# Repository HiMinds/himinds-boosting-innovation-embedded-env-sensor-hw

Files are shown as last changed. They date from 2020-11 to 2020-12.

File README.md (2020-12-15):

# himinds-env-sensor-hw
HiMinds Open Source Wireless Environmental Sensor HW.

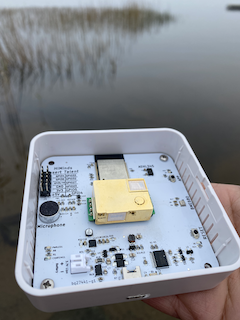
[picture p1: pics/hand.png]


## Rev B (G2)
The second generation of the hardware is based on the first version of the hardware but we have made several improvements. It is a rechargeable battery-operated wireless sensor that can measure:

* Carbon dioxide (CO₂) levels
* Temperature with ±1.0°C accuracy
* Barometric pressure with 1 hPa absolute accuracy
* Humidity with ±3% accuracy
* Volatile organic compounds (VOC) gas sensor
* Tamper detection
* Sound level meter 

The project is described in our [Medium articles](https://medium.com/himinds/himinds-wireless-environmental-sensor-gen-2-part-1-requirements-37ee416b31b).

The enclosure is called CBRS01VWH and is made by [CamdenBoss](https://www.camdenboss.com/). 

## Rev A (G1)

The first version of the hardware, was based on the work done by OLIMEX. Link to their [project page](https://github.com/OLIMEX/ESP32-DevKit-LiPo)
For other credits please refer to our [Medium ariticles](https://medium.com/himinds/open-source-wireless-environmental-sensor-part-1-requirements-8598c5b5f503).

## Open Source Hardware
The hardware is certified by OSHWA’s Open Source Hardware Certification program.
It is the first certification given to a Swedish project. 
* Rev A (Version 1.0) [OSHWA certification](https://certification.oshwa.org/se000001.html)
* Rev B (Version 2.0) [OSHWA certification](https://certification.oshwa.org/se000007.html)

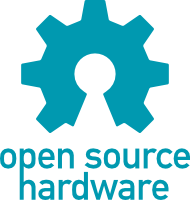
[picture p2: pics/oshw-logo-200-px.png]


## License
* Hardware is released under Apache 2.0 License
* Documentation is released under CC BY-SA 3.0

## Disclaimer of Warranties and Limitation of Liability. (from CC 3.0)

### Representations, Warranties and Disclaimer

UNLESS OTHERWISE MUTUALLY AGREED TO BY THE PARTIES IN WRITING, LICENSOR OFFERS THE WORK AS-IS AND MAKES NO REPRESENTATIONS OR WARRANTIES OF ANY KIND CONCERNING THE WORK, EXPRESS, IMPLIED, STATUTORY OR OTHERWISE, INCLUDING, WITHOUT LIMITATION, WARRANTIES OF TITLE, MERCHANTIBILITY, FITNESS FOR A PARTICULAR PURPOSE, NONINFRINGEMENT, OR THE ABSENCE OF LATENT OR OTHER DEFECTS, ACCURACY, OR THE PRESENCE OF ABSENCE OF ERRORS, WHETHER OR NOT DISCOVERABLE. SOME JURISDICTIONS DO NOT ALLOW THE EXCLUSION OF IMPLIED WARRANTIES, SO SUCH EXCLUSION MAY NOT APPLY TO YOU.

### Limitation on Liability. 
EXCEPT TO THE EXTENT REQUIRED BY APPLICABLE LAW, IN NO EVENT WILL LICENSOR BE LIABLE TO YOU ON ANY LEGAL THEORY FOR ANY SPECIAL, INCIDENTAL, CONSEQUENTIAL, PUNITIVE OR EXEMPLARY DAMAGES ARISING OUT OF THIS LICENSE OR THE USE OF THE WORK, EVEN IF LICENSOR HAS BEEN ADVISED OF THE POSSIBILITY OF SUCH DAMAGES.

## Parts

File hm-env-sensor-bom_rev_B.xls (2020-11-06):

Id | Designator | Package | Quantity | Designation
1 | C22,C21,C20,C18 | C_0603_5MIL_DWS | 4 | 10uF/6.3V/X7R/C0603
2 | J1 | PinHeader_2x06_P2.54mm_Vertical | 1 | Conn_02x06_Odd_Even
3 | U7 | PDSO-N12 | 1 | BQ27441-G1
4 | USB-UART1 | USB_Micro_B_Male_UJ2-MIBH-4-SMT-TR | 1 | MISB-SWMM-5B-LF(USB_MICRO)
5 | U11 | Texas_S-PVSON-N10_ThermalVias | 1 | TPS61202DRC
6 | U10 | SOT-353_SC-70-5 | 1 | MAX4466
7 | U9 | SOT-23-5 | 1 | SY8089AAAC(SOT23-5)
8 | U8 | MH-Z19B | 1 | MH-Z19B
9 | U6 | Bosch_LGA-8_3x3mm_P0.8mm_ClockwisePinNumbering | 1 | BME680
10 | U4 | SOT-23-5 | 1 | BL4054B-42TPRN(SOT23-5)
11 | U3 | SOT23-3 | 1 | BAT54C(SOT23-3)
12 | U2 | SSOP-20W | 1 | CH340T(SSOP20W)
13 | U1 | LGA-14_3x5mm_P0.8mm_LayoutBorder1x6y | 1 | ADXL345
14 | R33,R32,R11,R14 | R_0603_5MIL_DWS | 4 | NA/R0603
15 | R31 | R_0603_5MIL_DWS | 1 | 10k
16 | R30 | R_0603_5MIL_DWS | 1 | 20k/R0603
17 | R29,R25,R23,R5,R4,R13 | R_0603_5MIL_DWS | 6 | 1k/R0603
18 | R28,R27 | R_0603_5MIL_DWS | 2 | 1M/R0603
19 | R21 | R_0603_5MIL_DWS | 1 | 1.1k/1%/R0603
20 | R20,R17,R16,R15,R8 | R_0603_5MIL_DWS | 5 | 4.7k/R0603
21 | R19,R9,R7,R26 | R_0603_5MIL_DWS | 4 | 10k/R0603
22 | R18 | R_1206_5MIL_DWS | 1 | 0.01/1%/R1206
23 | R12 | R_0603_5MIL_DWS | 1 | 4.99k/1%/R0603
24 | R10 | R_0603_5MIL_DWS | 1 | 2.2k/R0603
25 | R6,R3,R2 | R_0603_5MIL_DWS | 3 | 220R/R0603
26 | R1,R22,R24 | R_0603_5MIL_DWS | 3 | 330/R0603
27 | Q3,Q2 | SOT23 | 2 | BC817-40(SOT23)
28 | Q1 | TSX-3.2x2.5mm_GND(3) | 1 | Q12MHz/20pF/10ppm/4P/3.2x2.5mm
29 | PWRLED1,D4 | LED_0603_KA | 2 | LED/GREEN/0603
30 | MK1 | MIC_CMA-4544PF-W | 1 | Microphone
31 | L2 | L_Wuerth_MAPI-3015 | 1 | LPS3015-222ML
32 | L1 | CD32 | 1 | 2.2uH/1.5A/DCR<0.1R/CD32
33 | FET1 | SOT23 | 1 | WPM2015-3/TR
34 | FB2,FB1 | L_0603_5MIL_DWS | 2 | Ferrite_Bead_Small
35 | D2,D1 | SMA-KA | 2 | 1N5822/SS34/SMA
36 | CHARGING1 | LED_0603_KA | 1 | LED/YELLOW/0603
37 | C19 | C_0603_5MIL_DWS | 1 | 1uF/6.3V/X7R/C0603
38 | C17,C12,C7 | C_0805_5MIL_DWS | 3 | 47uF/6.3V/20%/X5R/C0805
39 | C16 | C_0603_5MIL_DWS | 1 | 100pF/C0603
40 | C15 | C_0603_5MIL_DWS | 1 | 10uF/C0603
41 | C14 | C_0603_5MIL_DWS | 1 | 10nF/50V/20%/Y5V/C0603
42 | C13,C9,C8,C6,C2 | C_0603_5MIL_DWS | 5 | 100nF/50V/20%/Y5V/C0603
43 | C11 | C_0603_5MIL_DWS | 1 | 0.47uF/50V/20%/Y5V/C0603
44 | C10 | C_0603_5MIL_DWS | 1 | 1.0uF/16V/10%/Y5V/C0603
45 | C5 | C_0603_5MIL_DWS | 1 | 22uF/6.3V/20%/X5R/C0603
46 | C4,C3 | C_0603_5MIL_DWS | 2 | 27pF/50V/5%/C0G/C0603
47 | C1 | C_0603_5MIL_DWS | 1 | 4.7uF/50V/20%/Y5V/C0603
48 | BAT1 | LIPO_BAT-CON2DW02R | 1 | DW02S
49 | RST1,RST2 | IT1185AU2_V2 | 2 | IT-1185AU2-160G-G-TR
50 | U5 | ESP-WROOM-32_MODULE | 1 | ESP-WROOM-32
51 | D6 | LED_0603_KA | 1 | LED/RED/0603

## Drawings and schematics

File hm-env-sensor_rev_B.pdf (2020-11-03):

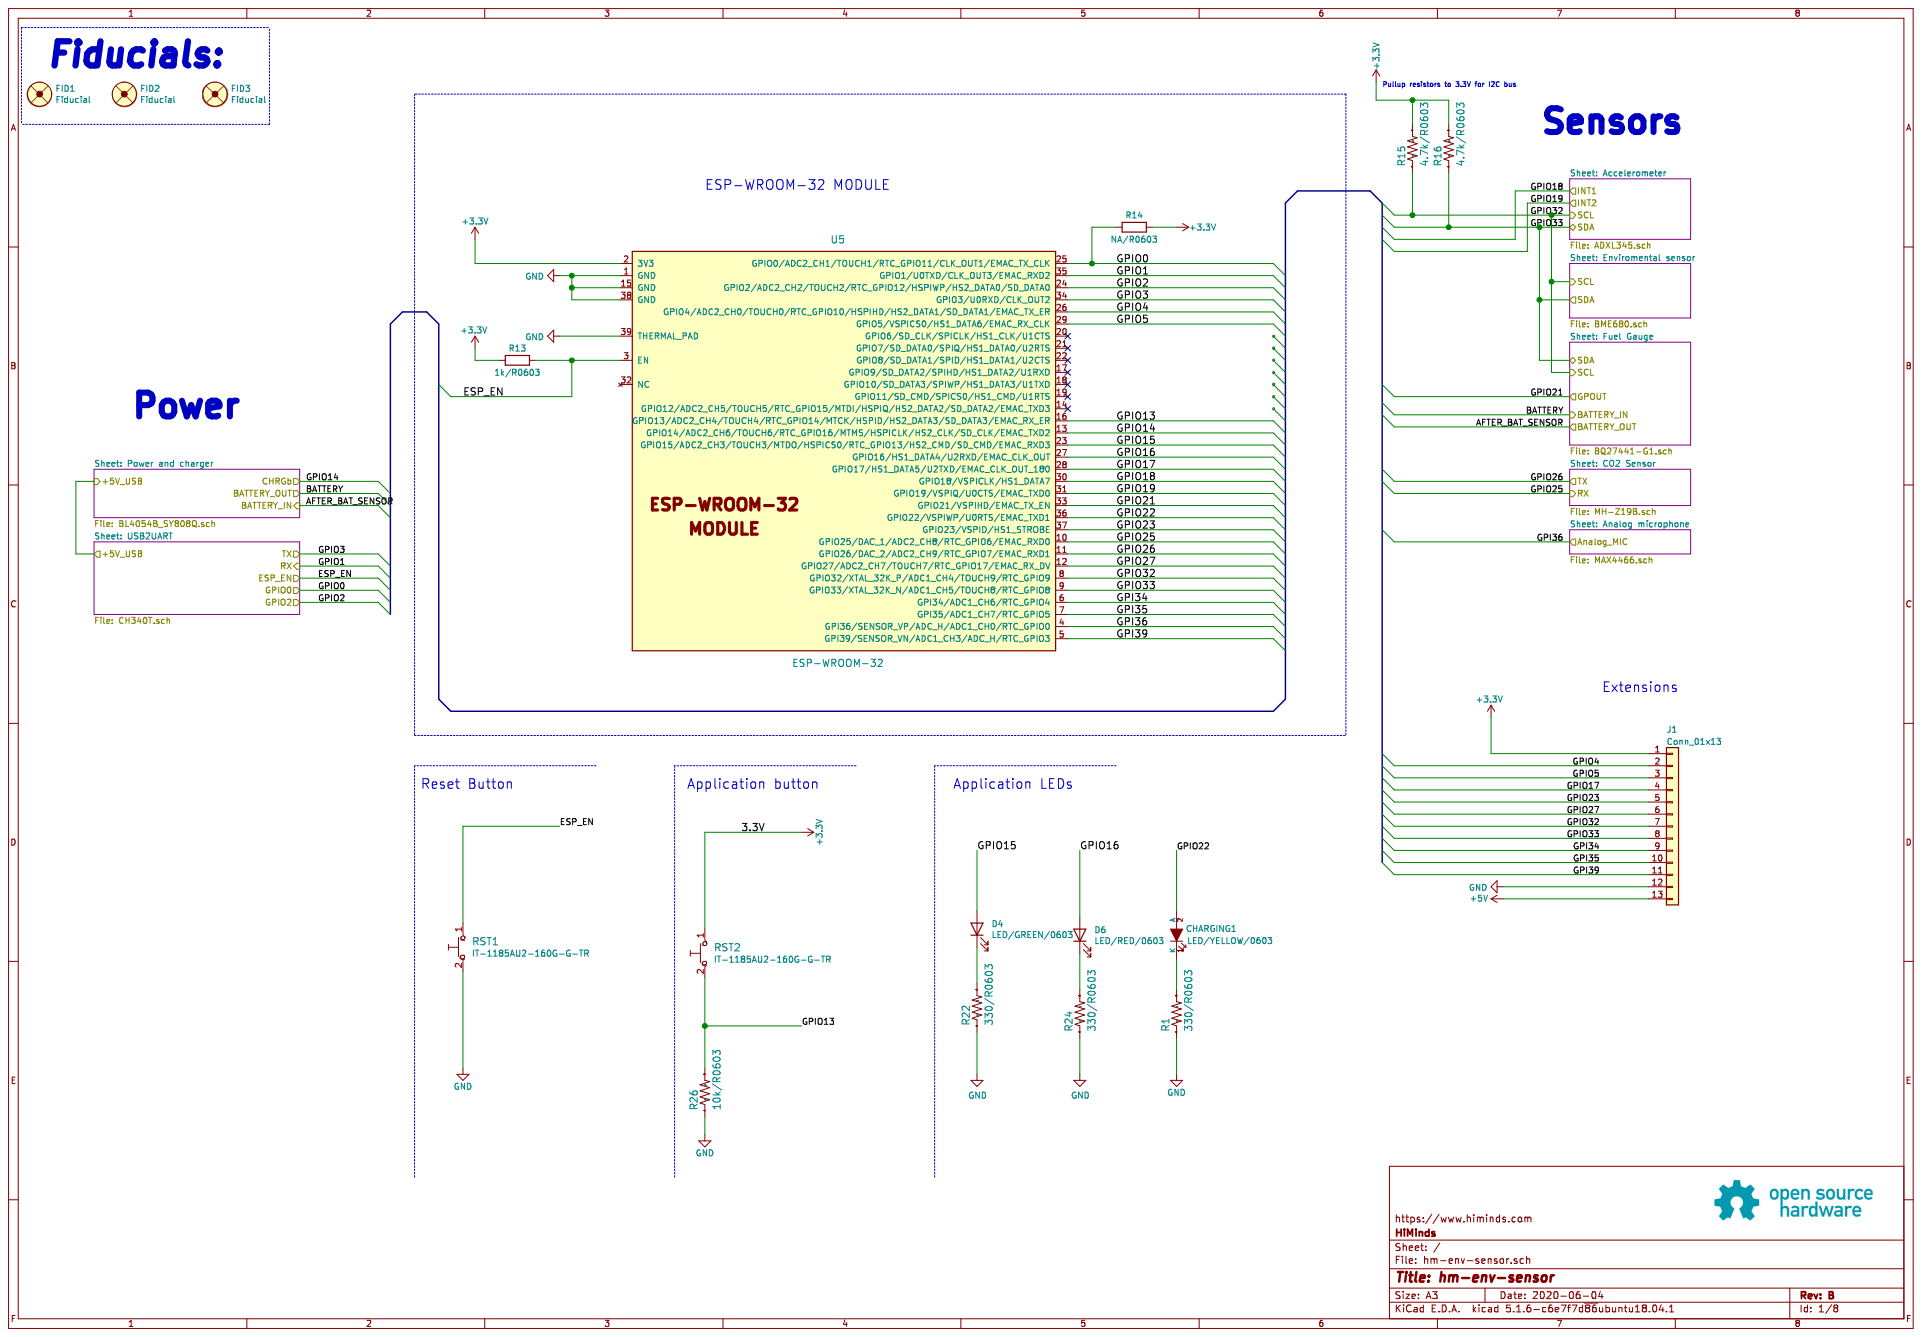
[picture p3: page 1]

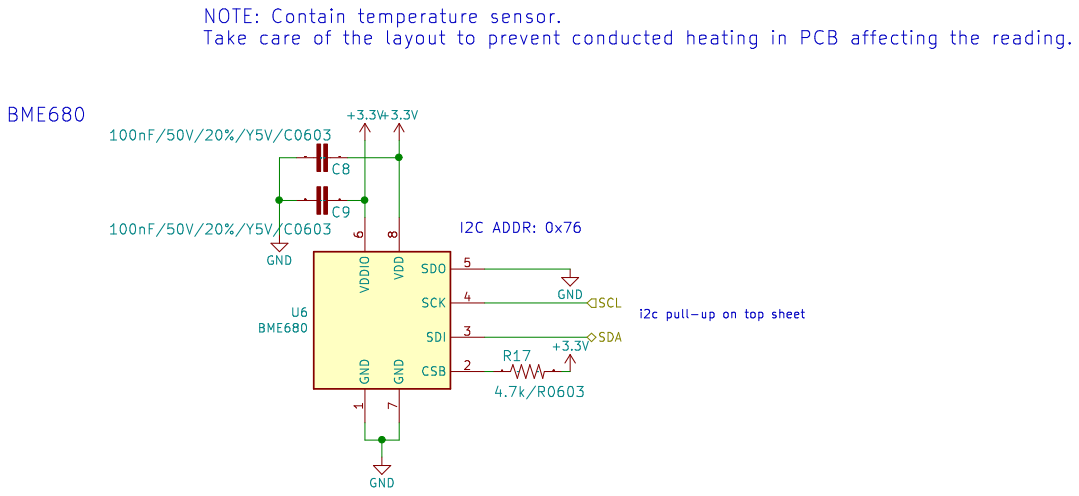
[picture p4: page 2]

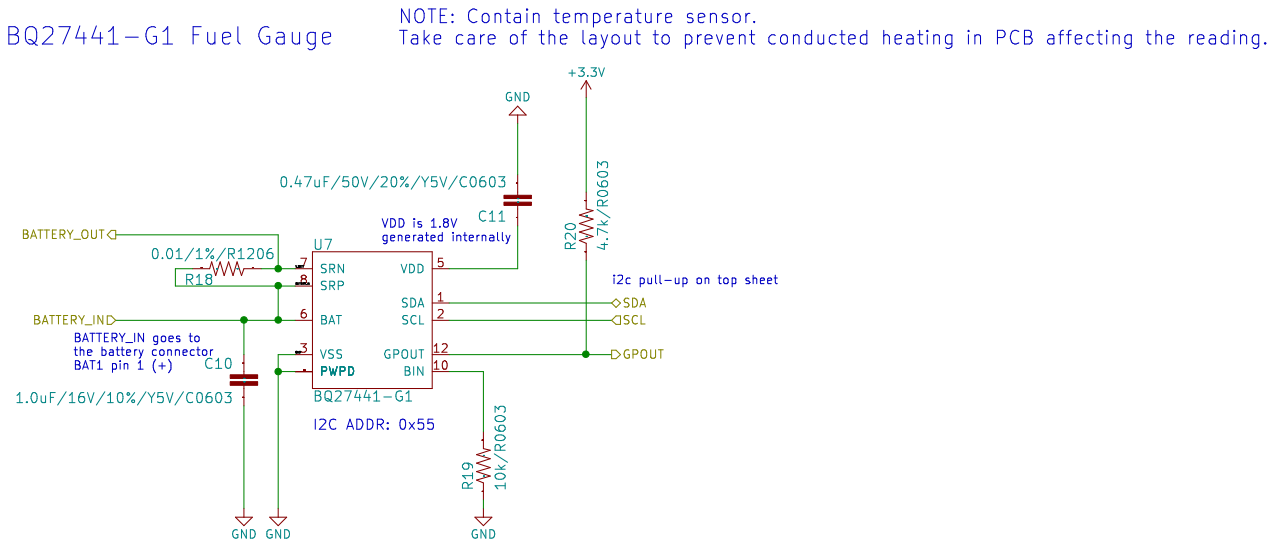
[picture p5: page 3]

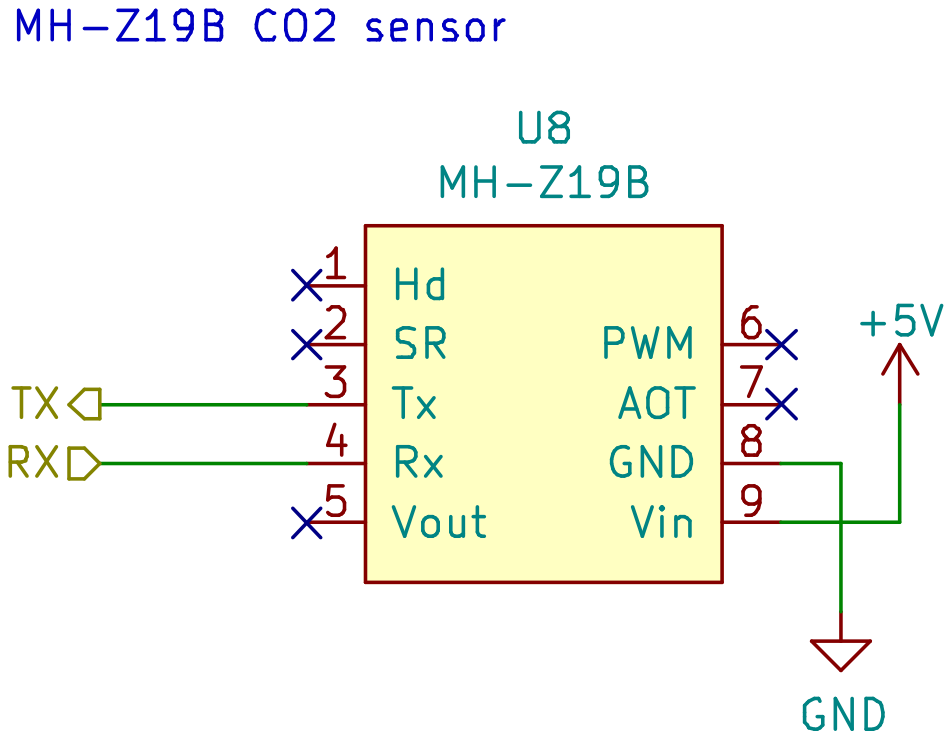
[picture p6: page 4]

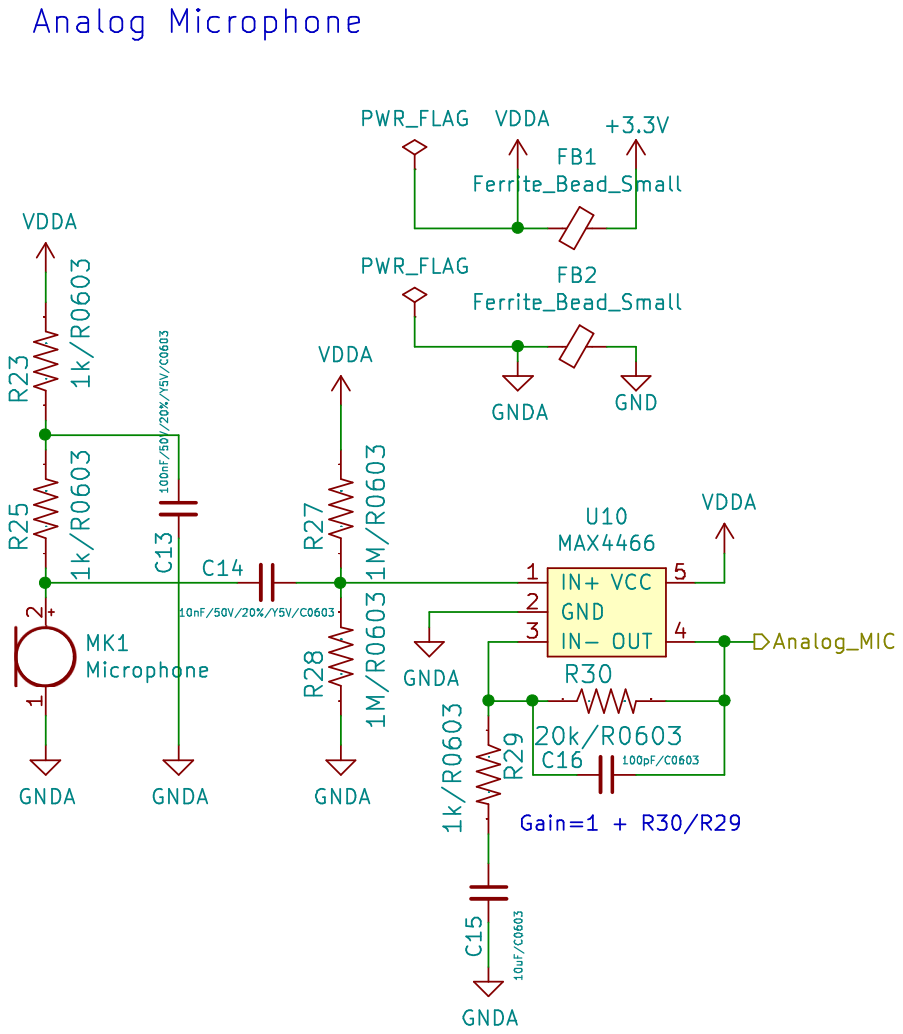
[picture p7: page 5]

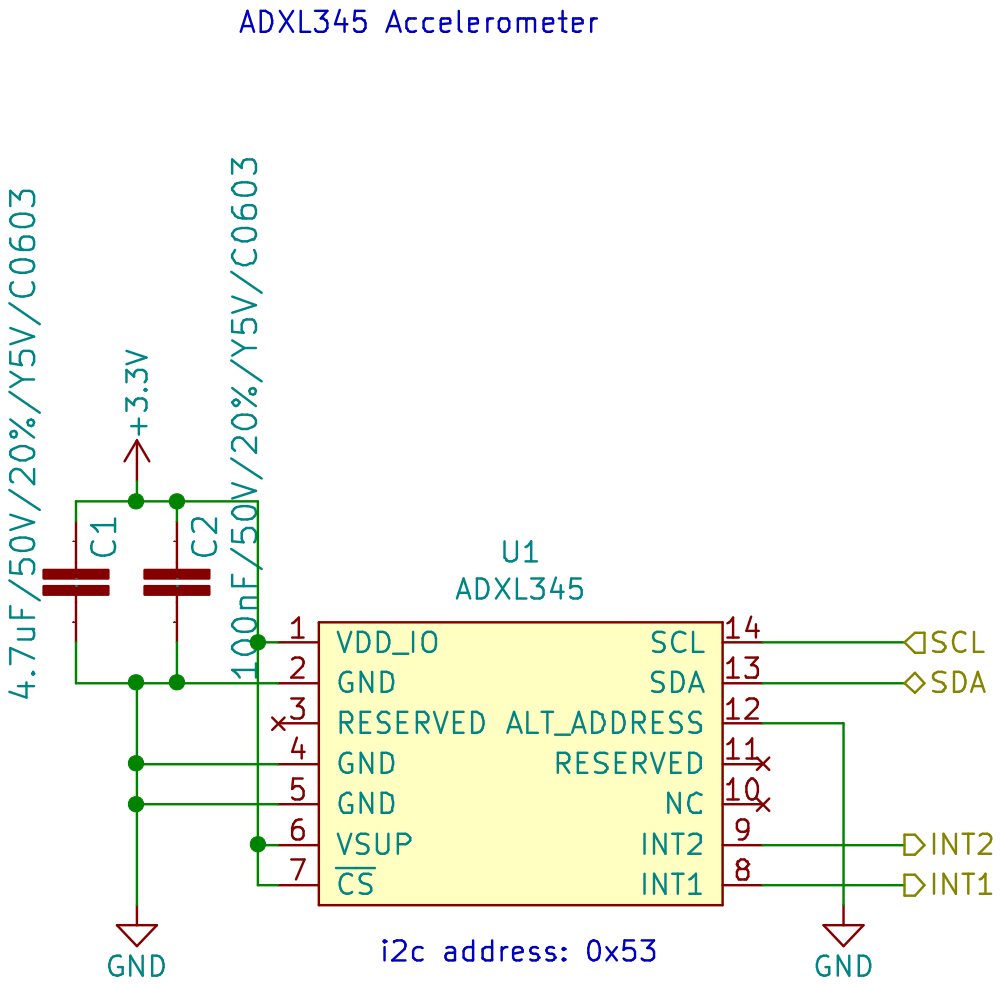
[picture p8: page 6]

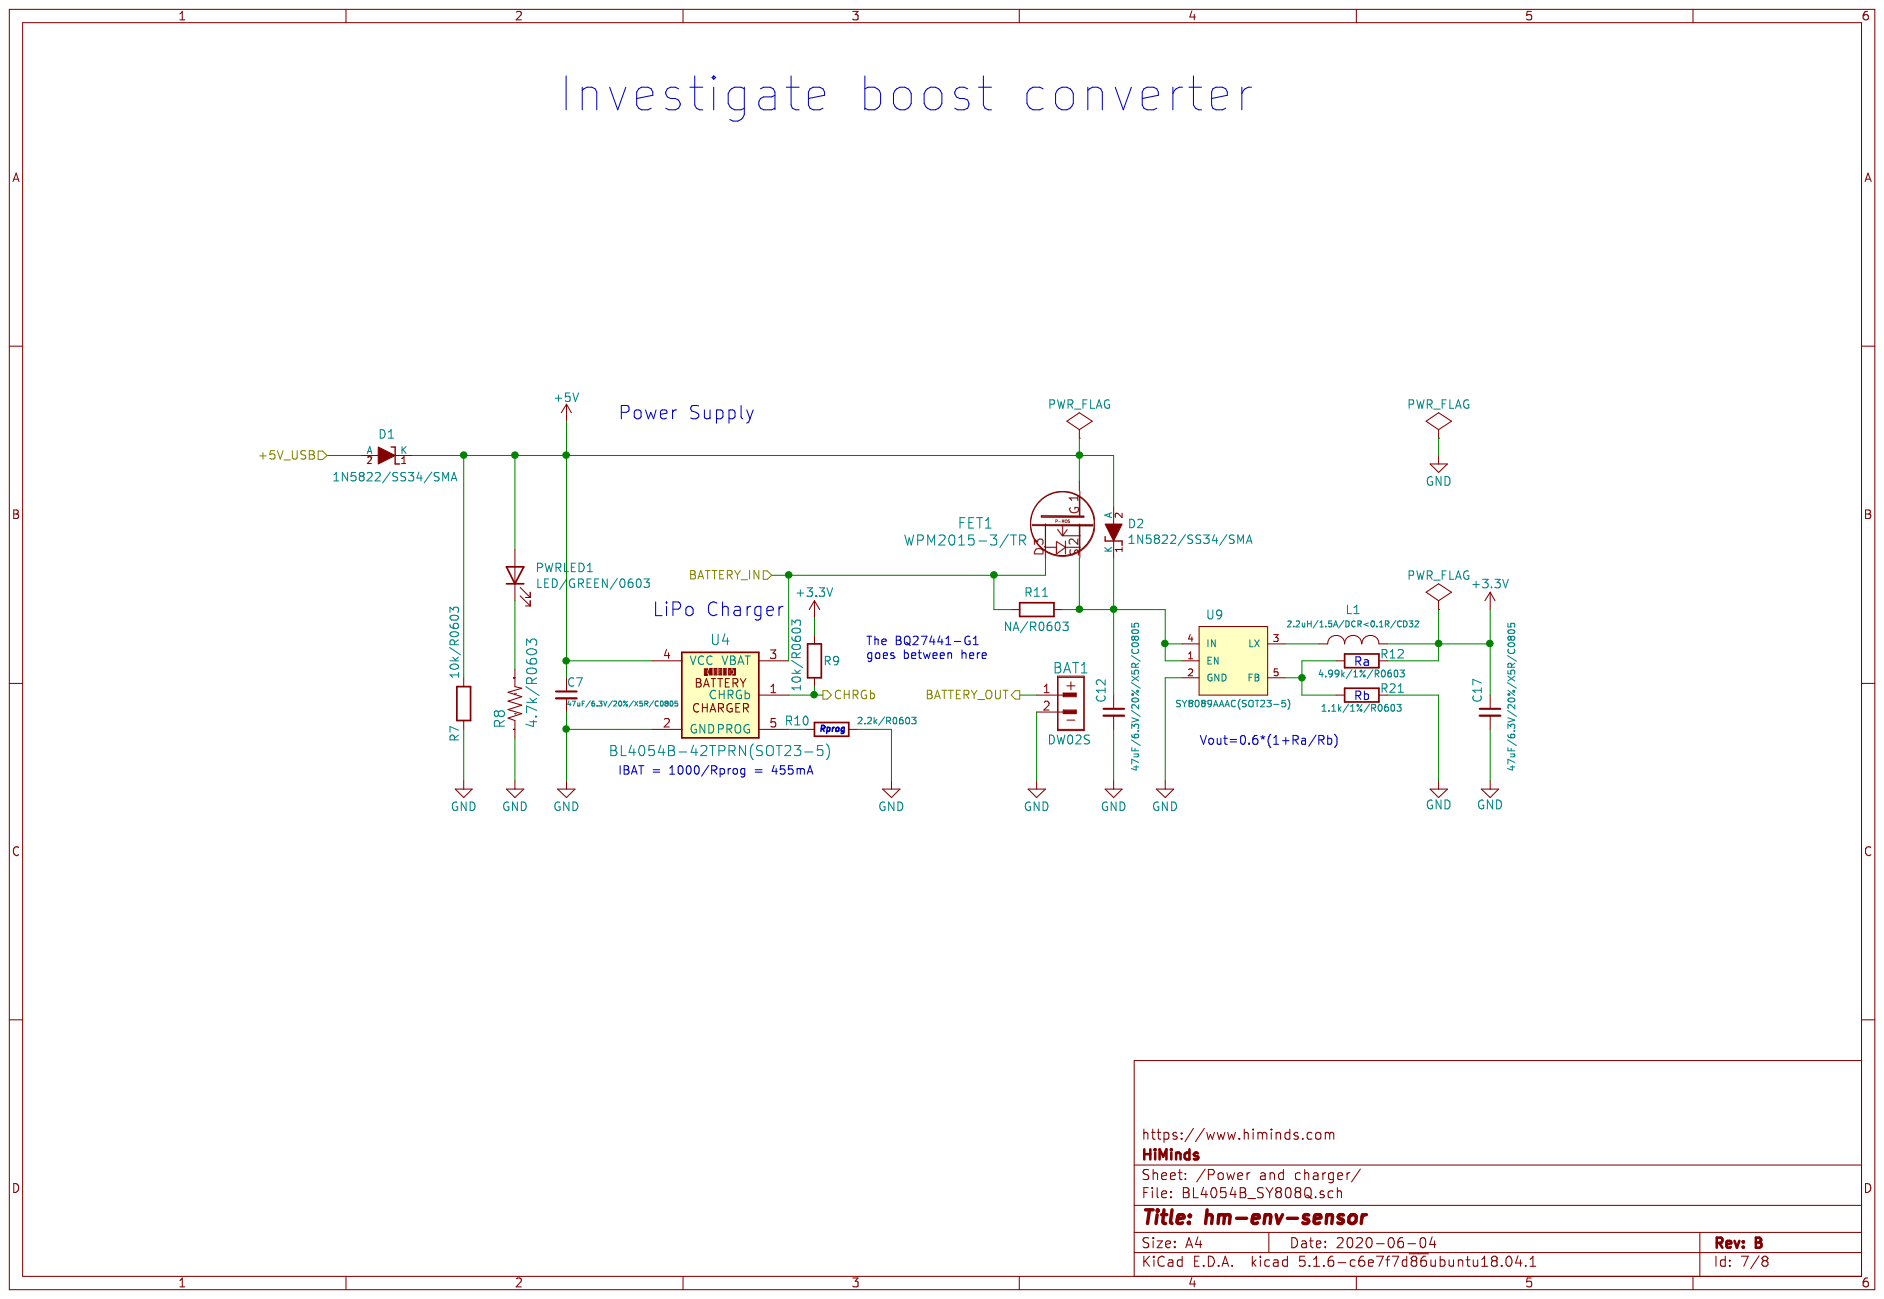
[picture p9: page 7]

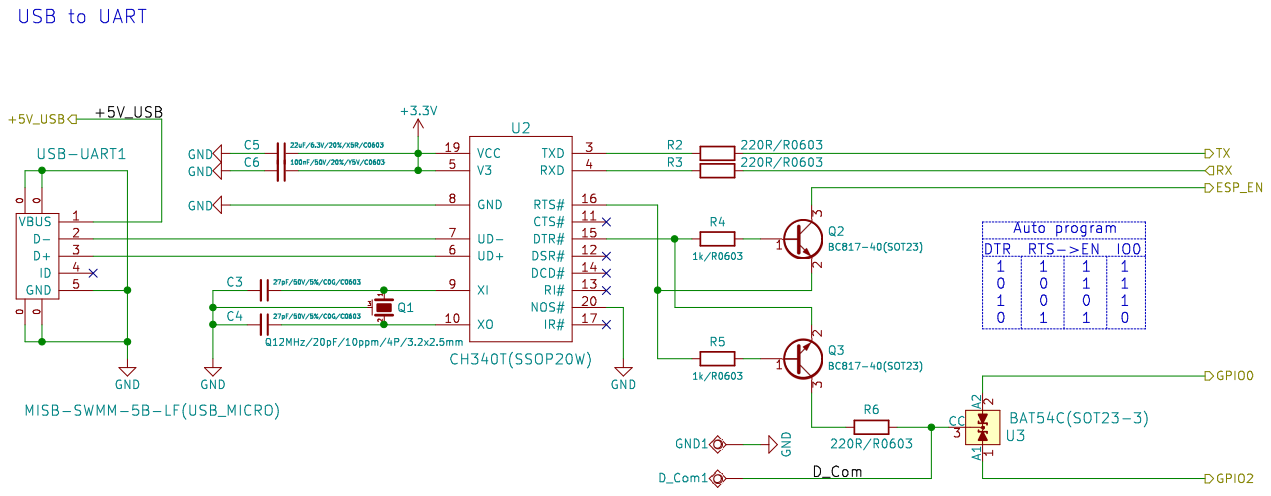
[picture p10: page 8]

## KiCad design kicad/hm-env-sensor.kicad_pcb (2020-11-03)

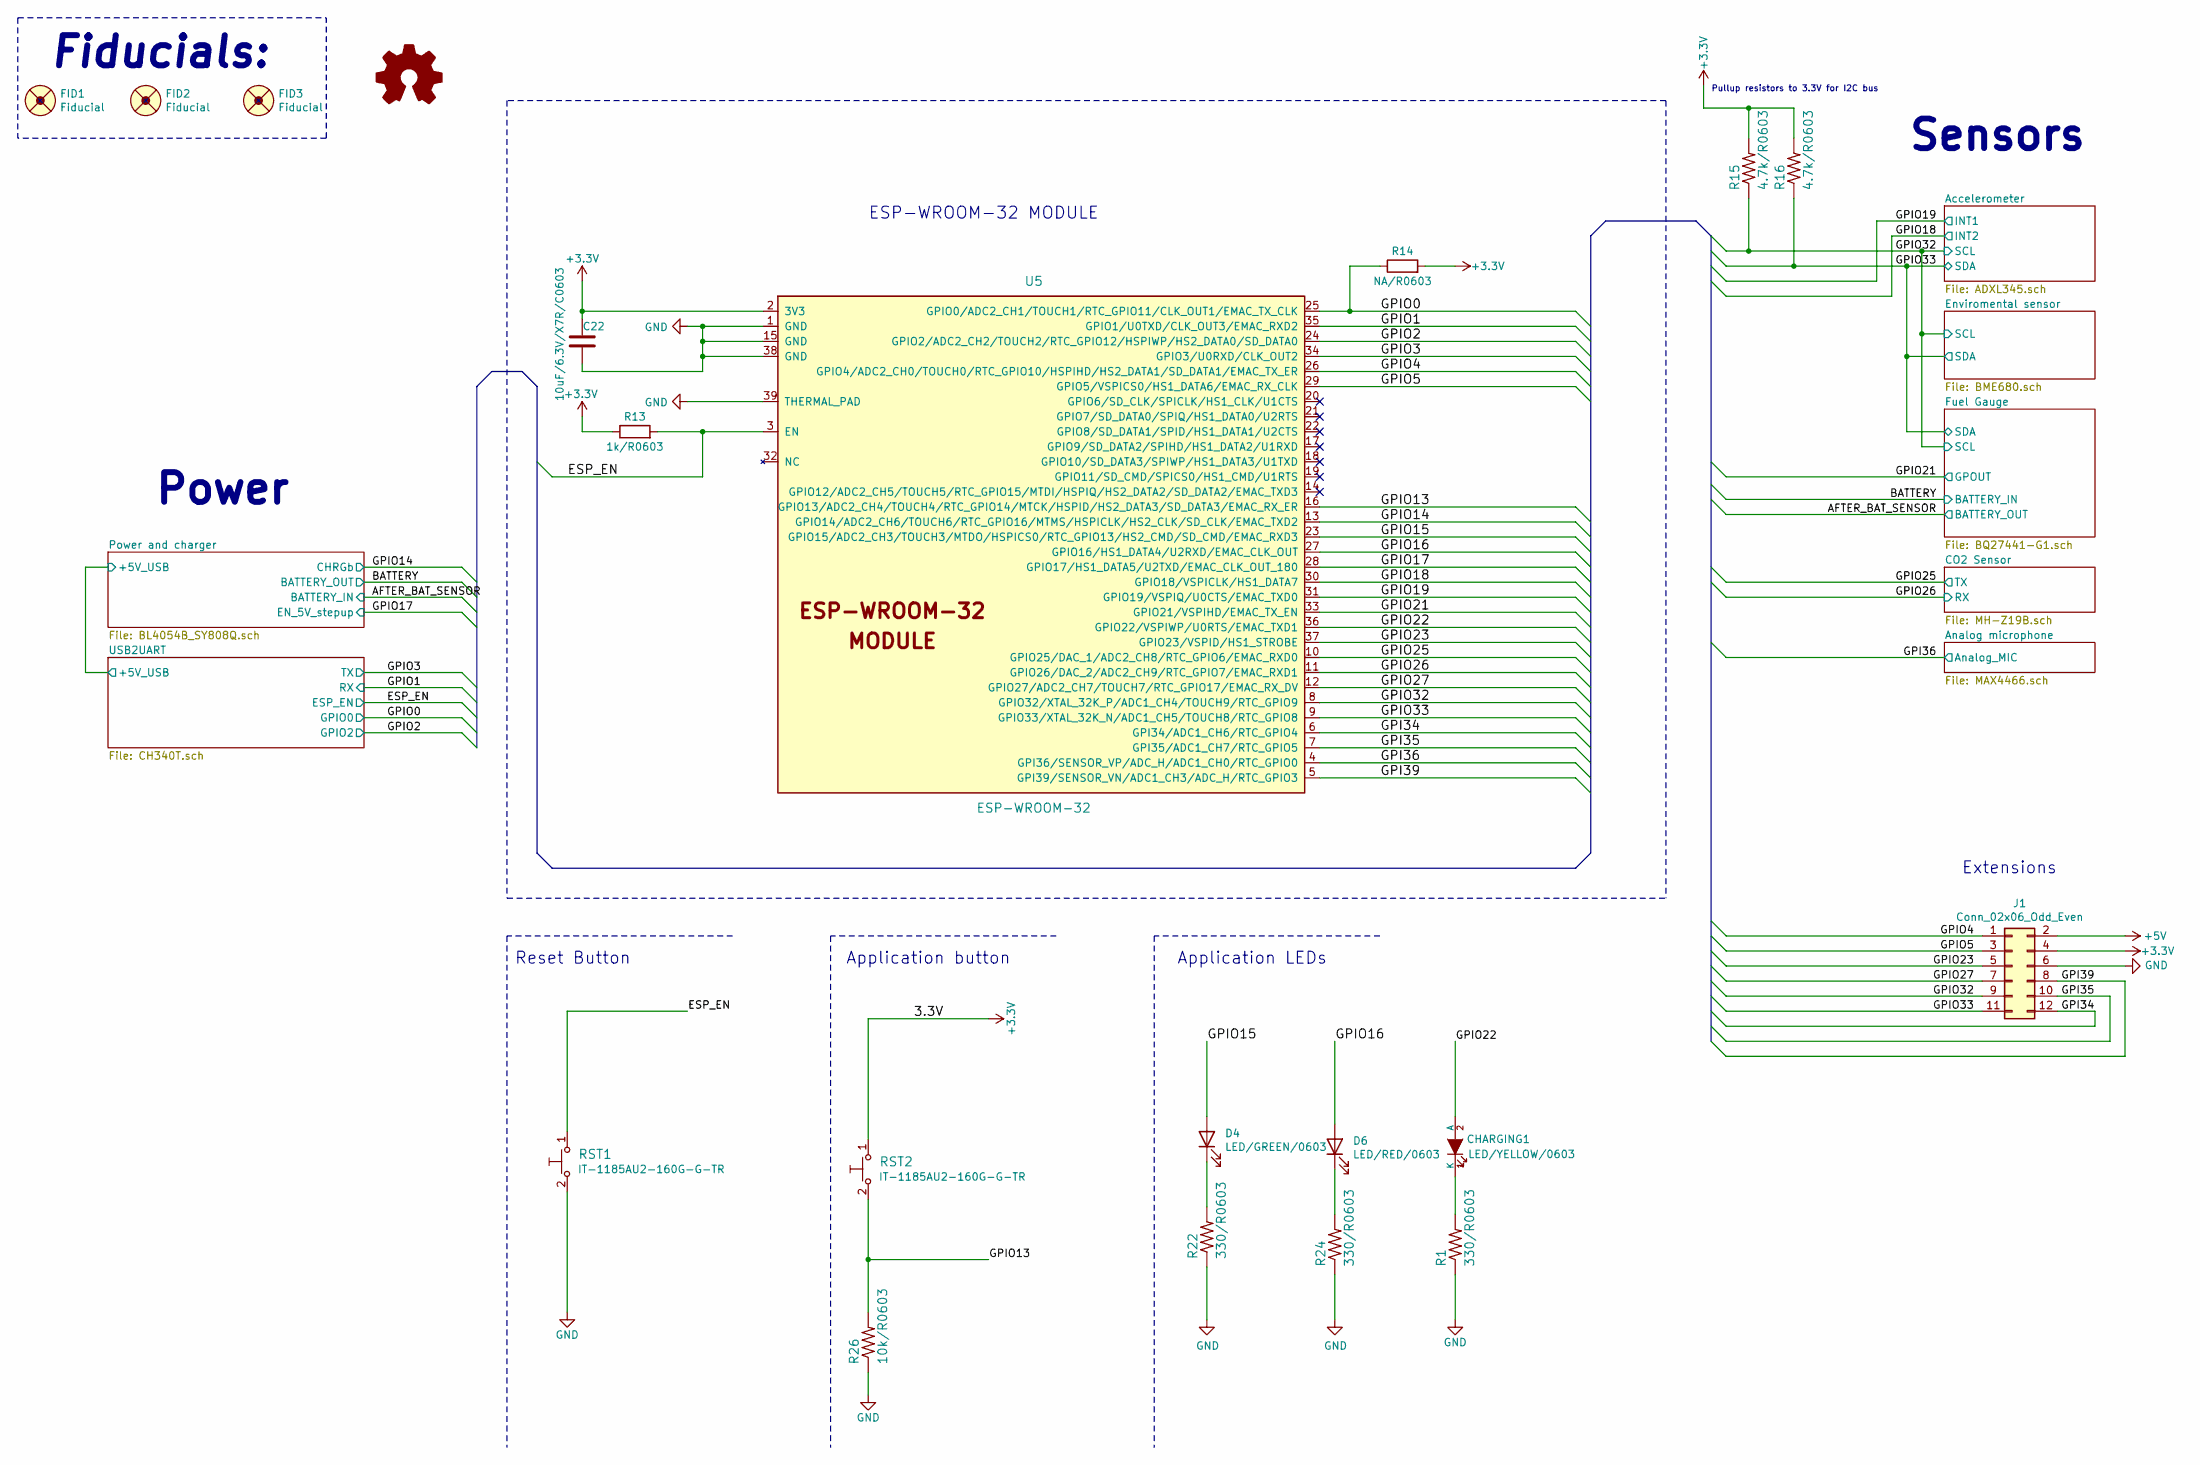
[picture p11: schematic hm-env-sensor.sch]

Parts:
C22: 10uF/6.3V/X7R/C0603; C_0603_5MIL_DWS
CHARGING1: LED/YELLOW/0603; LED_0603_KA
D4: LED/GREEN/0603; LED_0603_KA
D6: LED/RED/0603; LED_0603_KA
FID1, FID2, FID3: Fiducial; Fiducial1x3
J1: Conn_02x06_Odd_Even; PinHeader_2x06_P2.54mm_Vertical
R1, R22, R24: 330/R0603; R_0603_5MIL_DWS
R13: 1k/R0603; R_0603_5MIL_DWS
R14: NA/R0603; R_0603_5MIL_DWS
R15, R16: 4.7k/R0603; R_0603_5MIL_DWS
R26: 10k/R0603; R_0603_5MIL_DWS
RST1, RST2: IT-1185AU2-160G-G-TR; IT1185AU2_V2
U5: ESP-WROOM-32; ESP-WROOM-32_MODULE

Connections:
+3V3: C22.1, J1.4, R13.1, R14.2, R15.2, R16.2, RST2.1, U5.2 (3V3); also elsewhere on the board
+5V: J1.2; also elsewhere on the board
/ESP_EN: R13.2, RST1.1, U5.3 (EN); also elsewhere on the board
/GPI34: J1.12, U5.6 (GPI34/ADC1_CH6/RTC_GPIO4)
/GPI35: J1.10, U5.7 (GPI35/ADC1_CH7/RTC_GPIO5)
/GPI36: U5.4 (GPI36/SENSOR_VP/ADC_H/ADC1_CH0/RTC_GPIO0); also elsewhere on the board
/GPI39: J1.8, U5.5 (GPI39/SENSOR_VN/ADC1_CH3/ADC_H/RTC_GPIO3)
/GPIO0: R14.1, U5.25 (GPIO0/ADC2_CH1/TOUCH1/RTC_GPIO11/CLK_OU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); also elsewhere on the board
/GPIO1: U5.35 (GPIO1/U0TXD/CLK_OUT3/EMAC_RXD2); also elsewhere on the board
/GPIO2: U5.24 (GPIO2/ADC2_CH2/TOUCH2/RTC_GPIO12/HSPIWP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); also elsewhere on the board
/GPIO3: U5.34 (GPIO3/U0RXD/CLK_OUT2); also elsewhere on the board
/GPIO4: J1.1, U5.26 (GPIO4/ADC2_CH0/TOUCH0/RTC_GPIO10/HSPIHD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)
/GPIO5: J1.3, U5.29 (GPIO5/VSPICS0/HS1_DATA6/EMAC_RX_CLK)
/GPIO13: R26.2, RST2.2, U5.16 (GPIO13/ADC2_CH4/TOUCH4/RTC_GPIO14/MTCK/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)
/GPIO14: U5.13 (GPIO14/ADC2_CH6/TOUCH6/RTC_GPIO16/MTMS/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); also elsewhere on the board
/GPIO15: D4.2 (A), U5.23 (GPIO15/ADC2_CH3/TOUCH3/MTDO/HSPICS0/RTC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)
/GPIO16: D6.2 (A), U5.27 (GPIO16/HS1_DATA4/U2RXD/EMAC_CLK_OUT)
/GPIO17: U5.28 (GPIO17/HS1_DATA5/U2TXD/EMAC_CLK_OUT_180); also elsewhere on the board
/GPIO18: U5.30 (GPIO18/VSPICLK/HS1_DATA7); also elsewhere on the board
/GPIO19: U5.31 (GPIO19/VSPIQ/U0CTS/EMAC_TXD0); also elsewhere on the board
/GPIO21: U5.33 (GPIO21/VSPIHD/EMAC_TX_EN); also elsewhere on the board
/GPIO22: CHARGING1.2 (A), U5.36 (GPIO22/VSPIWP/U0RTS/EMAC_TXD1)
/GPIO23: J1.5, U5.37 (GPIO23/VSPID/HS1_STROBE)
/GPIO25: U5.10 (GPIO25/DAC_1/ADC2_CH8/RTC_GPIO6/EMAC_RX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); also elsewhere on the board
/GPIO26: U5.11 (GPIO26/DAC_2/ADC2_CH9/RTC_GPIO7/EMAC_RX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); also elsewhere on the board
/GPIO27: J1.7, U5.12 (GPIO27/ADC2_CH7/TOUCH7/RTC_GPIO17/EMAC_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)
/GPIO32: J1.9, R15.1, U5.8 (GPIO32/XTAL_32K_P/ADC1_CH4/TOUCH9/RTC_G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); also elsewhere on the board
/GPIO33: J1.11, R16.1, U5.9 (GPIO33/XTAL_32K_N/ADC1_CH5/TOUCH8/RTC_G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); also elsewhere on the board
GND: C22.2, J1.6, R1.1, R22.1, R24.1, R26.1, RST1.2, U5.1 (GND), U5.15 (GND), U5.38 (GND), U5.39 (THERMAL_PAD); also elsewhere on the board
unnamed: CHARGING1.1 (K), R1.2
unnamed: D4.1 (K), R22.2
unnamed: D6.1 (K), R24.2

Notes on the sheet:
Fiducials:
ESP-WROOM-32 MODULE
Application button
Application LEDs
Reset Button
Pullup resistors to 3.3V for I2C bus
Extensions
Sensors
Power

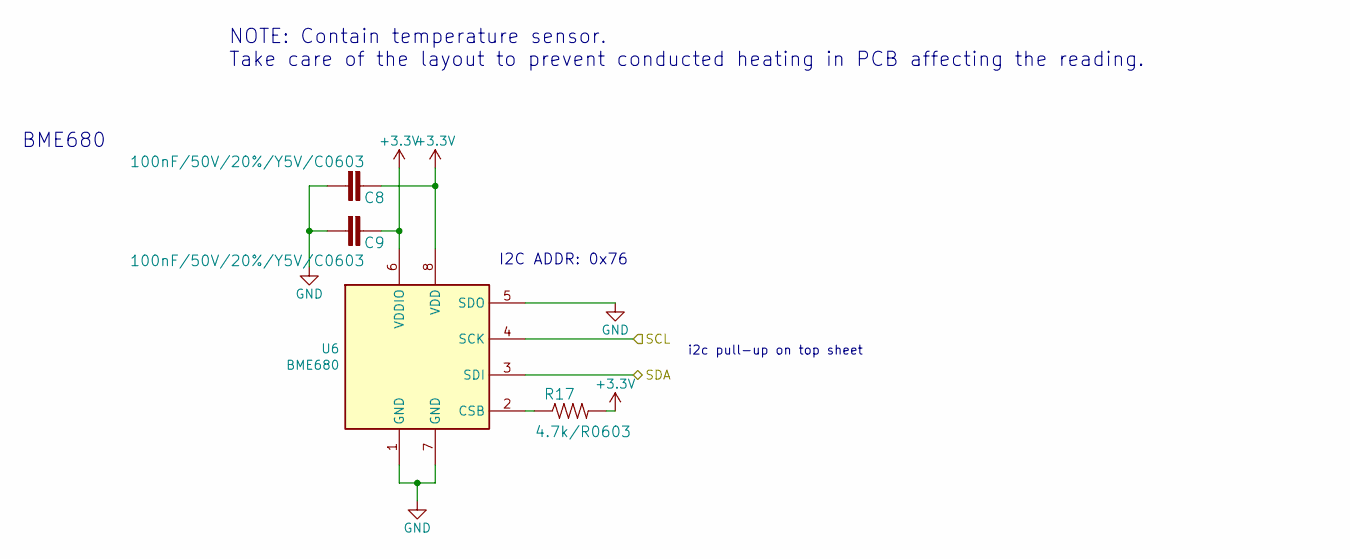
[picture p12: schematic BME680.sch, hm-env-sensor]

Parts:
C8, C9: 100nF/50V/20%/Y5V/C0603; C_0603_5MIL_DWS
R17: 4.7k/R0603; R_0603_5MIL_DWS
U6: BME680; Bosch_LGA-8_3x3mm_P0.8mm_ClockwisePinNumbering

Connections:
+3V3: C8.1, C9.1, R17.2, U6.6 (VDDIO), U6.8 (VDD); also elsewhere on the board
/GPIO32: U6.4 (SCK); also elsewhere on the board
/GPIO33: U6.3 (SDI); also elsewhere on the board
GND: C8.2, C9.2, U6.1 (GND), U6.5 (SDO), U6.7 (GND); also elsewhere on the board
unnamed: R17.1, U6.2 (CSB)

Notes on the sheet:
I2C ADDR: 0x76
BME680
i2c pull-up on top sheet
NOTE: Contain temperature sensor. Take care of the layout to prevent conducted heating in PCB affecting the reading.

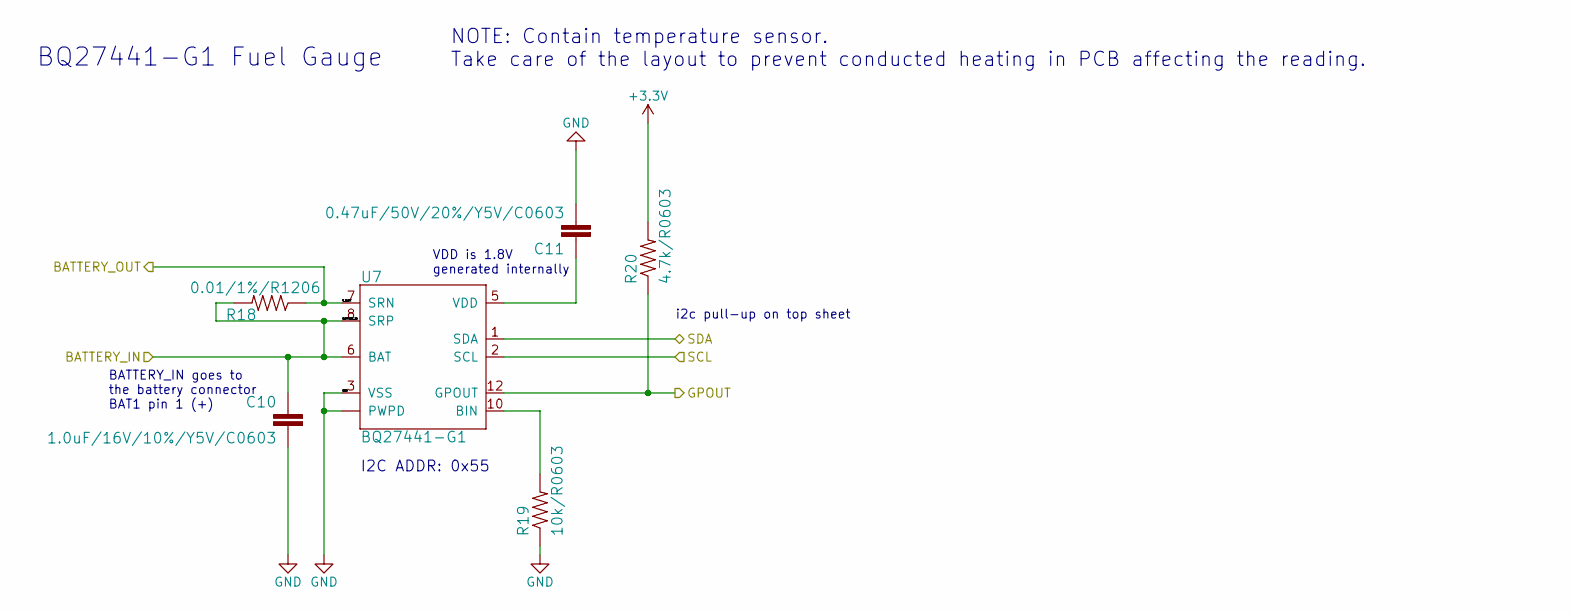
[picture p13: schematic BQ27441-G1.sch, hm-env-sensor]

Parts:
C10: 1.0uF/16V/10%/Y5V/C0603; C_0603_5MIL_DWS
C11: 0.47uF/50V/20%/Y5V/C0603; C_0603_5MIL_DWS
R18: 0.01/1%/R1206; R_1206_5MIL_DWS
R19: 10k/R0603; R_0603_5MIL_DWS
R20: 4.7k/R0603; R_0603_5MIL_DWS
U7: BQ27441-G1; PDSO-N12

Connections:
+3V3: R20.2; also elsewhere on the board
/AFTER_BAT_SENSOR: R18.1, U7.7 (SRN); also elsewhere on the board
/BATTERY: C10.1, R18.2, U7.6 (BAT), U7.8 (SRP); also elsewhere on the board
/GPIO21: R20.1, U7.12 (GPOUT); also elsewhere on the board
/GPIO32: U7.2 (SCL); also elsewhere on the board
/GPIO33: U7.1 (SDA); also elsewhere on the board
GND: C10.2, C11.2, R19.1, U7.3 (VSS), U7.EP (PWPD), U7.EP1 (PWPD), U7.EP2 (PWPD), U7.EP3 (PWPD), U7.EP4 (PWPD); also elsewhere on the board
unnamed: C11.1, U7.5 (VDD)
unnamed: R19.2, U7.10 (BIN)

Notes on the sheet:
I2C ADDR: 0x55
VDD is 1.8V generated internally
BQ27441-G1 Fuel Gauge
BATTERY_IN goes to the battery connector BAT1 pin 1 (+)
i2c pull-up on top sheet
NOTE: Contain temperature sensor. Take care of the layout to prevent conducted heating in PCB affecting the reading.

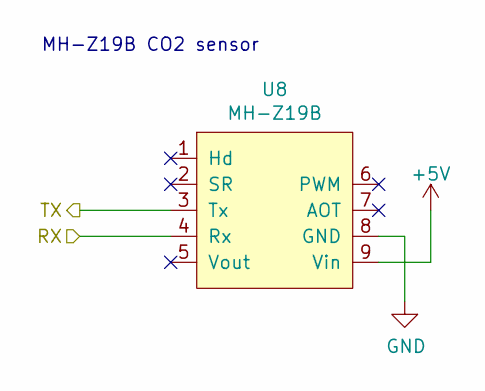
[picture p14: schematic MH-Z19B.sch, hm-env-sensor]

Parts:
U8: MH-Z19B

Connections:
+5V: U8.9 (Vin); also elsewhere on the board
/GPIO25: U8.3 (Tx); also elsewhere on the board
/GPIO26: U8.4 (Rx); also elsewhere on the board
GND: U8.8 (GND); also elsewhere on the board

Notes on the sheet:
MH-Z19B CO2 sensor

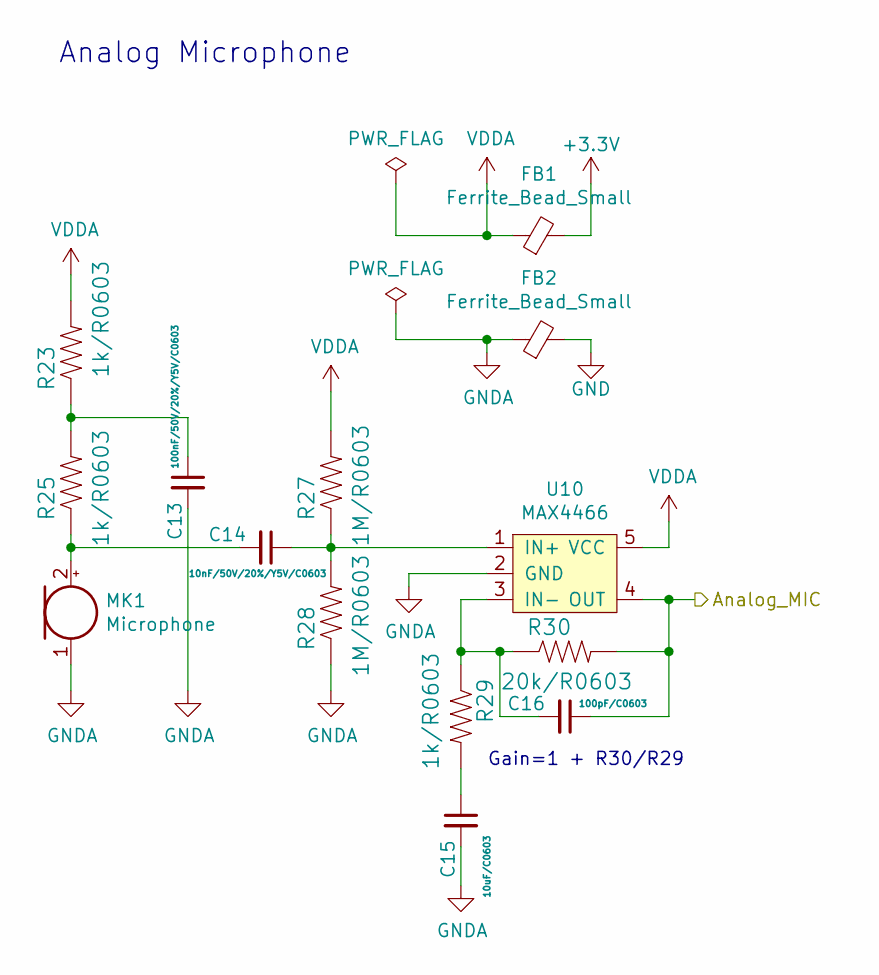
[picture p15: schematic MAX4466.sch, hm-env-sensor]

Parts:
C13: 100nF/50V/20%/Y5V/C0603; C_0603_5MIL_DWS
C14: 10nF/50V/20%/Y5V/C0603; C_0603_5MIL_DWS
C15: 10uF/C0603; C_0603_5MIL_DWS
C16: 100pF/C0603; C_0603_5MIL_DWS
FB1, FB2: Ferrite_Bead_Small; L_0603_5MIL_DWS
MK1: Microphone; MIC_CMA-4544PF-W
R23, R25, R29: 1k/R0603; R_0603_5MIL_DWS
R27, R28: 1M/R0603; R_0603_5MIL_DWS
R30: 20k/R0603; R_0603_5MIL_DWS
U10: MAX4466; SOT-353_SC-70-5

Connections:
+3V3: FB1.2; also elsewhere on the board
/GPI36: C16.1, R30.2, U10.4 (OUT); also elsewhere on the board
GND: FB2.2; also elsewhere on the board
GNDA: C13.2, C15.2, FB2.1, MK1.1 (-), R28.1, U10.2 (GND)
unnamed: C13.1, R23.1, R25.2
unnamed: C14.1, R27.1, R28.2, U10.1 (IN+)
unnamed: C14.2, MK1.2 (+), R25.1
unnamed: C15.1, R29.2
unnamed: C16.2, R29.1, R30.1, U10.3 (IN-)
VDDA: FB1.1, R23.2, R27.2, U10.5 (VCC)

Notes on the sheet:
Gain=1 + R30/R29
Analog Microphone

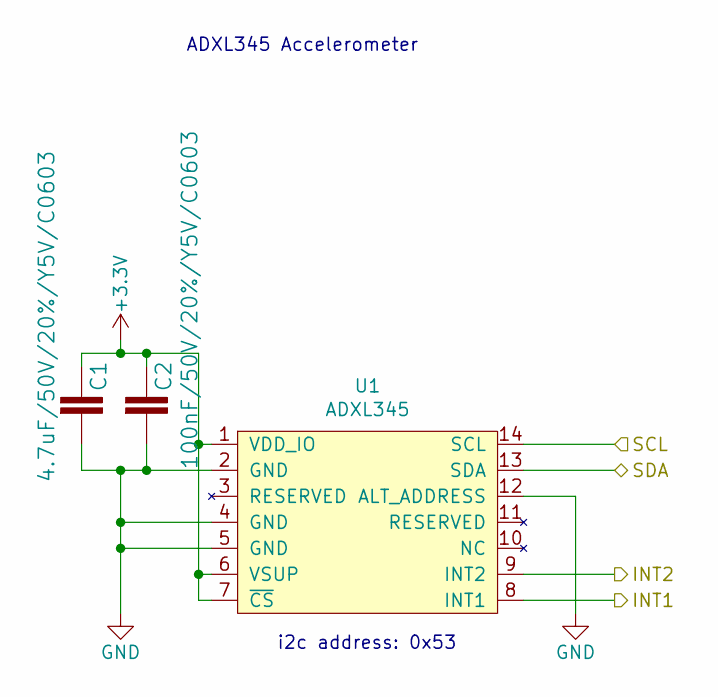
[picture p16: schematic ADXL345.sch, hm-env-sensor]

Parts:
C1: 4.7uF/50V/20%/Y5V/C0603; C_0603_5MIL_DWS
C2: 100nF/50V/20%/Y5V/C0603; C_0603_5MIL_DWS
U1: ADXL345; LGA-14_3x5mm_P0.8mm_LayoutBorder1x6y

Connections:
+3V3: C1.1, C2.1, U1.1 (VDD_IO), U1.6 (VSUP), U1.7 (~CS); also elsewhere on the board
/GPIO18: U1.9 (INT2); also elsewhere on the board
/GPIO19: U1.8 (INT1); also elsewhere on the board
/GPIO32: U1.14 (SCL); also elsewhere on the board
/GPIO33: U1.13 (SDA); also elsewhere on the board
GND: C1.2, C2.2, U1.2 (GND), U1.4 (GND), U1.5 (GND), U1.12 (ALT_ADDRESS); also elsewhere on the board

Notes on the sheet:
i2c address: 0x53
ADXL345 Accelerometer

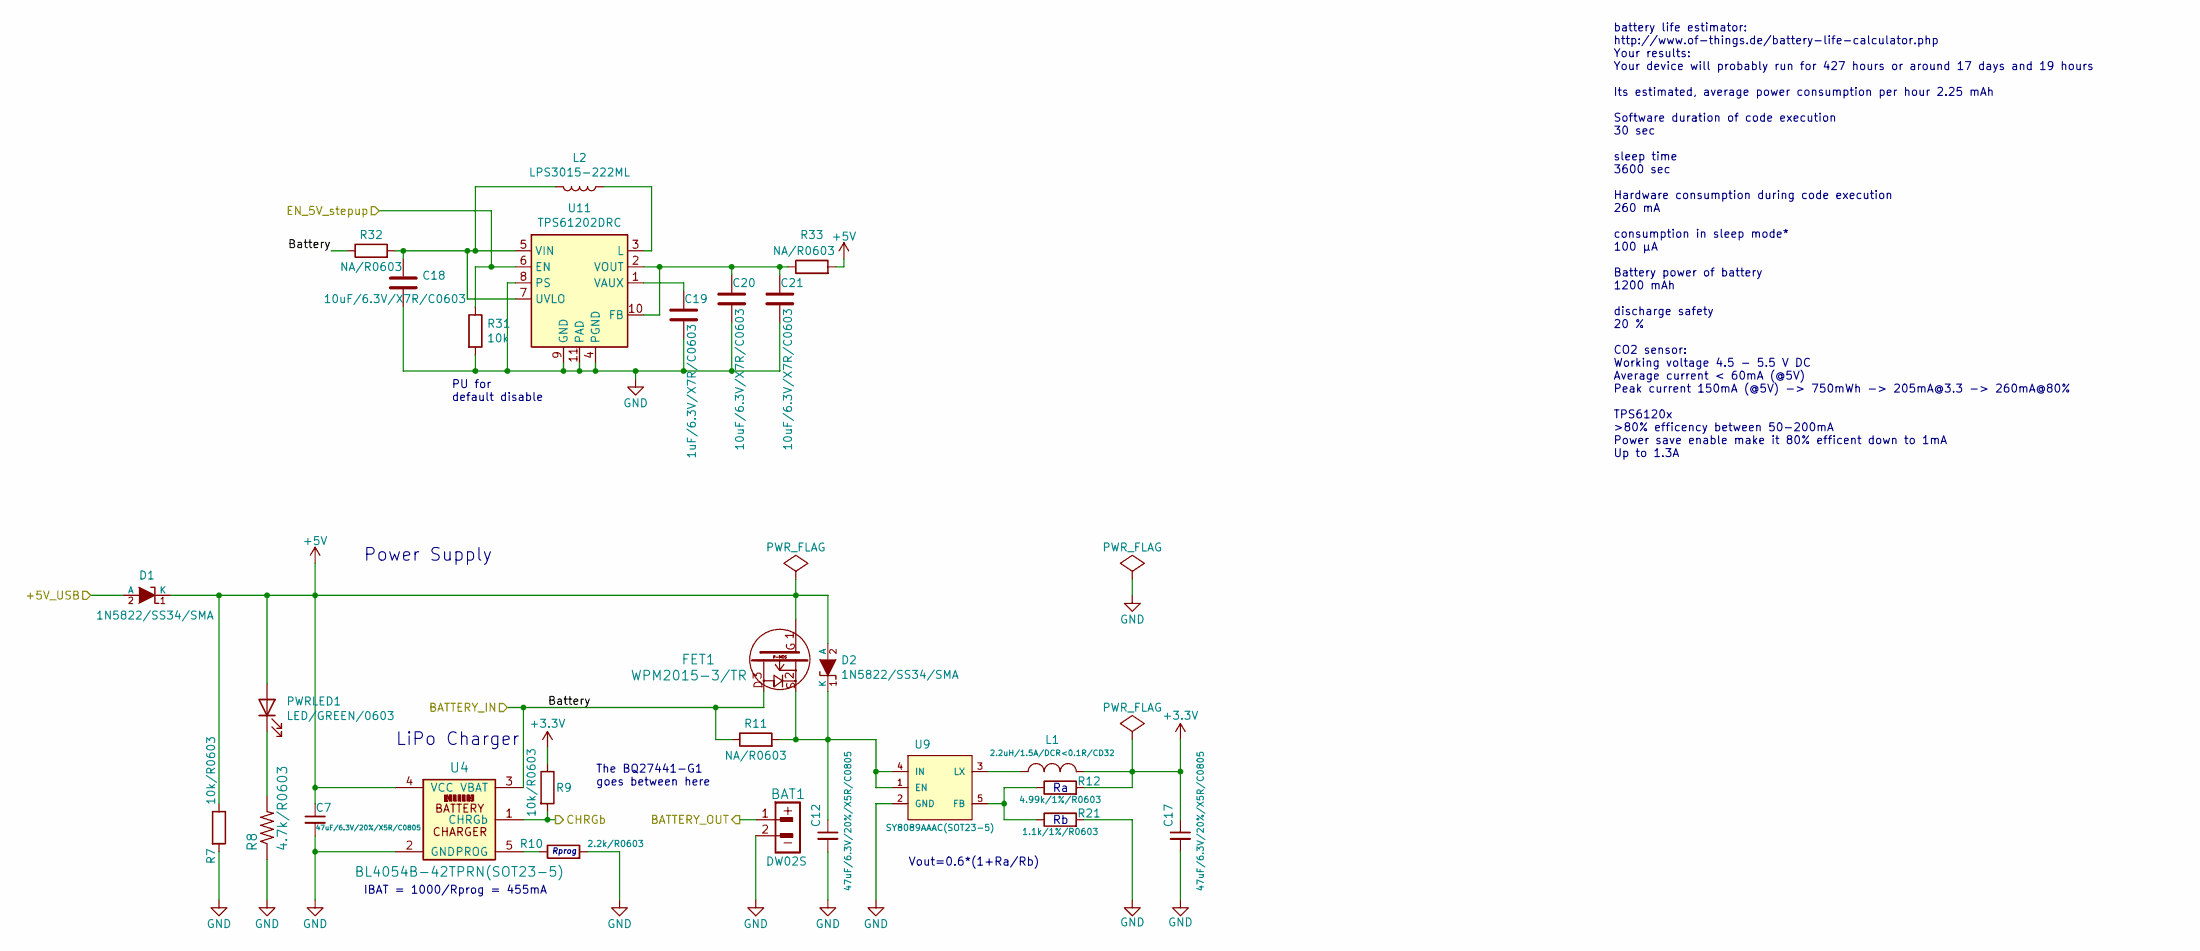
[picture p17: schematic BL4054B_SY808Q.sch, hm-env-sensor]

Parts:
BAT1: DW02S; LIPO_BAT-CON2DW02R
C7, C12, C17: 47uF/6.3V/20%/X5R/C0805; C_0805_5MIL_DWS
C18, C20, C21: 10uF/6.3V/X7R/C0603; C_0603_5MIL_DWS
C19: 1uF/6.3V/X7R/C0603; C_0603_5MIL_DWS
D1, D2: 1N5822/SS34/SMA; SMA-KA
FET1: WPM2015-3/TR; SOT23
L1: 2.2uH/1.5A/DCR<0.1R/CD32; CD32
L2: LPS3015-222ML; L_Wuerth_MAPI-3015
PWRLED1: LED/GREEN/0603; LED_0603_KA
R7, R9: 10k/R0603; R_0603_5MIL_DWS
R8: 4.7k/R0603; R_0603_5MIL_DWS
R10: 2.2k/R0603; R_0603_5MIL_DWS
R11, R32, R33: NA/R0603; R_0603_5MIL_DWS
R12: 4.99k/1%/R0603; R_0603_5MIL_DWS
R21: 1.1k/1%/R0603; R_0603_5MIL_DWS
R31: 10k; R_0603_5MIL_DWS
U4: BL4054B-42TPRN(SOT23-5); SOT-23-5
U9: SY8089AAAC(SOT23-5); SOT-23-5
U11: TPS61202DRC; Texas_S-PVSON-N10_ThermalVias

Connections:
+3V3: C17.1, L1.2, R9.1, R12.2; also elsewhere on the board
+5V: C7.1, D1.1 (K), D2.2 (A), FET1.1, PWRLED1.2 (A), R7.1, R33.2, U4.4 (VCC); also elsewhere on the board
/AFTER_BAT_SENSOR: FET1.3, R11.1, R32.1, U4.3 (VBAT); also elsewhere on the board
/BATTERY: BAT1.1; also elsewhere on the board
/GPIO14: R9.2, U4.1 (CHRGb); also elsewhere on the board
/GPIO17: R31.1, U11.6 (EN); also elsewhere on the board
/Power and charger/+5V_USB: D1.2 (A); also elsewhere on the board
GND: BAT1.2, C7.2, C12.2, C17.2, C18.2, C19.2, C20.2, C21.2, R7.2, R8.1, R10.2, R21.2, R31.2, U4.2 (GND), U9.2 (GND), U11.4 (PGND), U11.8 (PS), U11.9 (GND), U11.11 (PAD); also elsewhere on the board
unnamed: C12.1, D2.1 (K), FET1.2, R11.2, U9.1 (EN), U9.4 (IN)
unnamed: C18.1, L2.2, R32.2, U11.5 (VIN), U11.7 (UVLO)
unnamed: C19.1, U11.1 (VAUX)
unnamed: C20.1, C21.1, R33.1, U11.2 (VOUT), U11.10 (FB)
unnamed: L1.1, U9.3 (LX)
unnamed: L2.1, U11.3 (L)
unnamed: PWRLED1.1 (K), R8.2
unnamed: R10.1, U4.5 (PROG)
unnamed: R12.1, R21.1, U9.5 (FB)

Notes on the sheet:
Vout=0.6*(1+Ra/Rb)
Power Supply
LiPo Charger
IBAT = 1000/Rprog = 455mA
Rprog
The BQ27441-G1 goes between here
battery life estimator: http://www.of-things.de/battery-life-calculator.php Your results: Your device will probably run for 427 hours or around 17 days and 19 hours Its estimated, average power consumption per hour 2.25 mAh Software duration of code execution 30 sec sleep time 3600 sec Hardware con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
PU for default disable

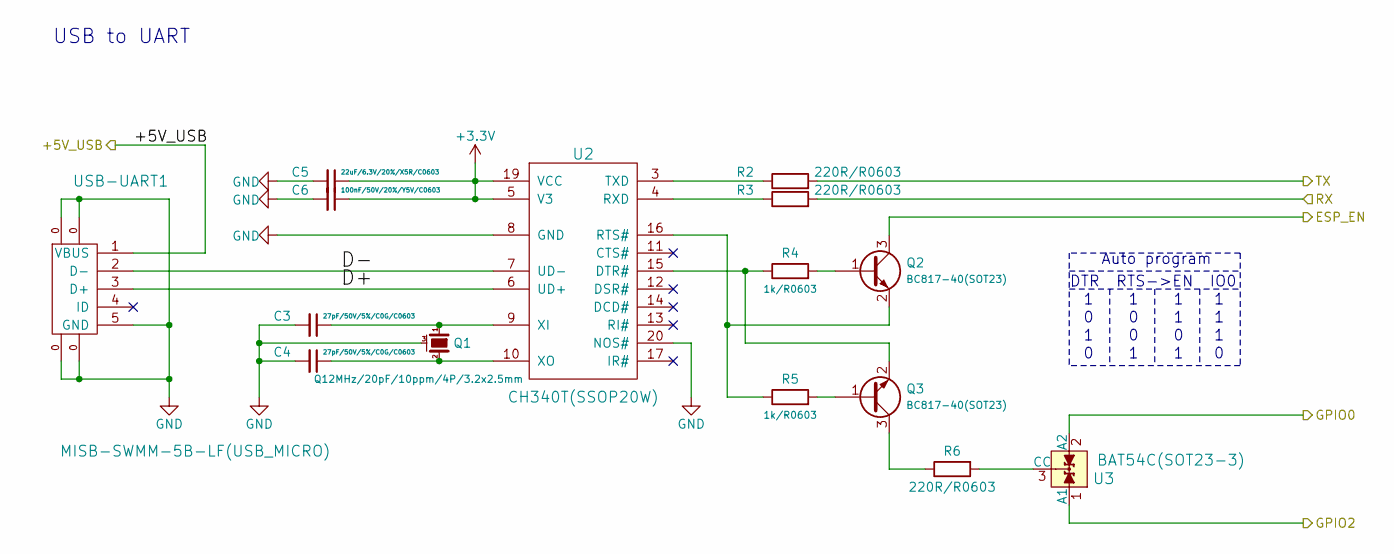
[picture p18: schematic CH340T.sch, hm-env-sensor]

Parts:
C3, C4: 27pF/50V/5%/C0G/C0603; C_0603_5MIL_DWS
C5: 22uF/6.3V/20%/X5R/C0603; C_0603_5MIL_DWS
C6: 100nF/50V/20%/Y5V/C0603; C_0603_5MIL_DWS
Q1: Q12MHz/20pF/10ppm/4P/3.2x2.5mm; TSX-3.2x2.5mm_GND(3)
Q2, Q3: BC817-40(SOT23); SOT23
R2, R3, R6: 220R/R0603; R_0603_5MIL_DWS
R4, R5: 1k/R0603; R_0603_5MIL_DWS
U2: CH340T(SSOP20W); SSOP-20W
U3: BAT54C(SOT23-3); SOT23-3
USB-UART1: MISB-SWMM-5B-LF(USB_MICRO); USB_Micro_B_Male_UJ2-MIBH-4-SMT-TR

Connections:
+3V3: C5.1, C6.1, U2.5 (V3), U2.19 (VCC); also elsewhere on the board
/ESP_EN: Q2.3 (C); also elsewhere on the board
/GPIO0: U3.2 (A2); also elsewhere on the board
/GPIO1: R3.2; also elsewhere on the board
/GPIO2: U3.1 (A1); also elsewhere on the board
/GPIO3: R2.2; also elsewhere on the board
/Power and charger/+5V_USB: USB-UART1.1 (VBUS); also elsewhere on the board
/USB2UART/D+: U2.6 (UD+), USB-UART1.3 (D+)
/USB2UART/D-: U2.7 (UD-), USB-UART1.2 (D-)
GND: C3.2, C4.2, C5.2, C6.2, Q1.3 (case), U2.8 (GND), U2.20 (NOS#), USB-UART1.0, USB-UART1.5 (GND); also elsewhere on the board
unnamed: C3.1, Q1.1, U2.9 (XI)
unnamed: C4.1, Q1.2, U2.10 (XO)
unnamed: Q2.1 (B), R4.2
unnamed: Q2.2 (E), R5.1, U2.16 (RTS#)
unnamed: Q3.1 (B), R5.2
unnamed: Q3.2 (E), R4.1, U2.15 (DTR#)
unnamed: Q3.3 (C), R6.1
unnamed: R2.1, U2.3 (TXD)
unnamed: R3.1, U2.4 (RXD)
unnamed: R6.2, U3.3 (CC)

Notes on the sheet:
Auto program
DTR RTS->EN IO0
USB to UART

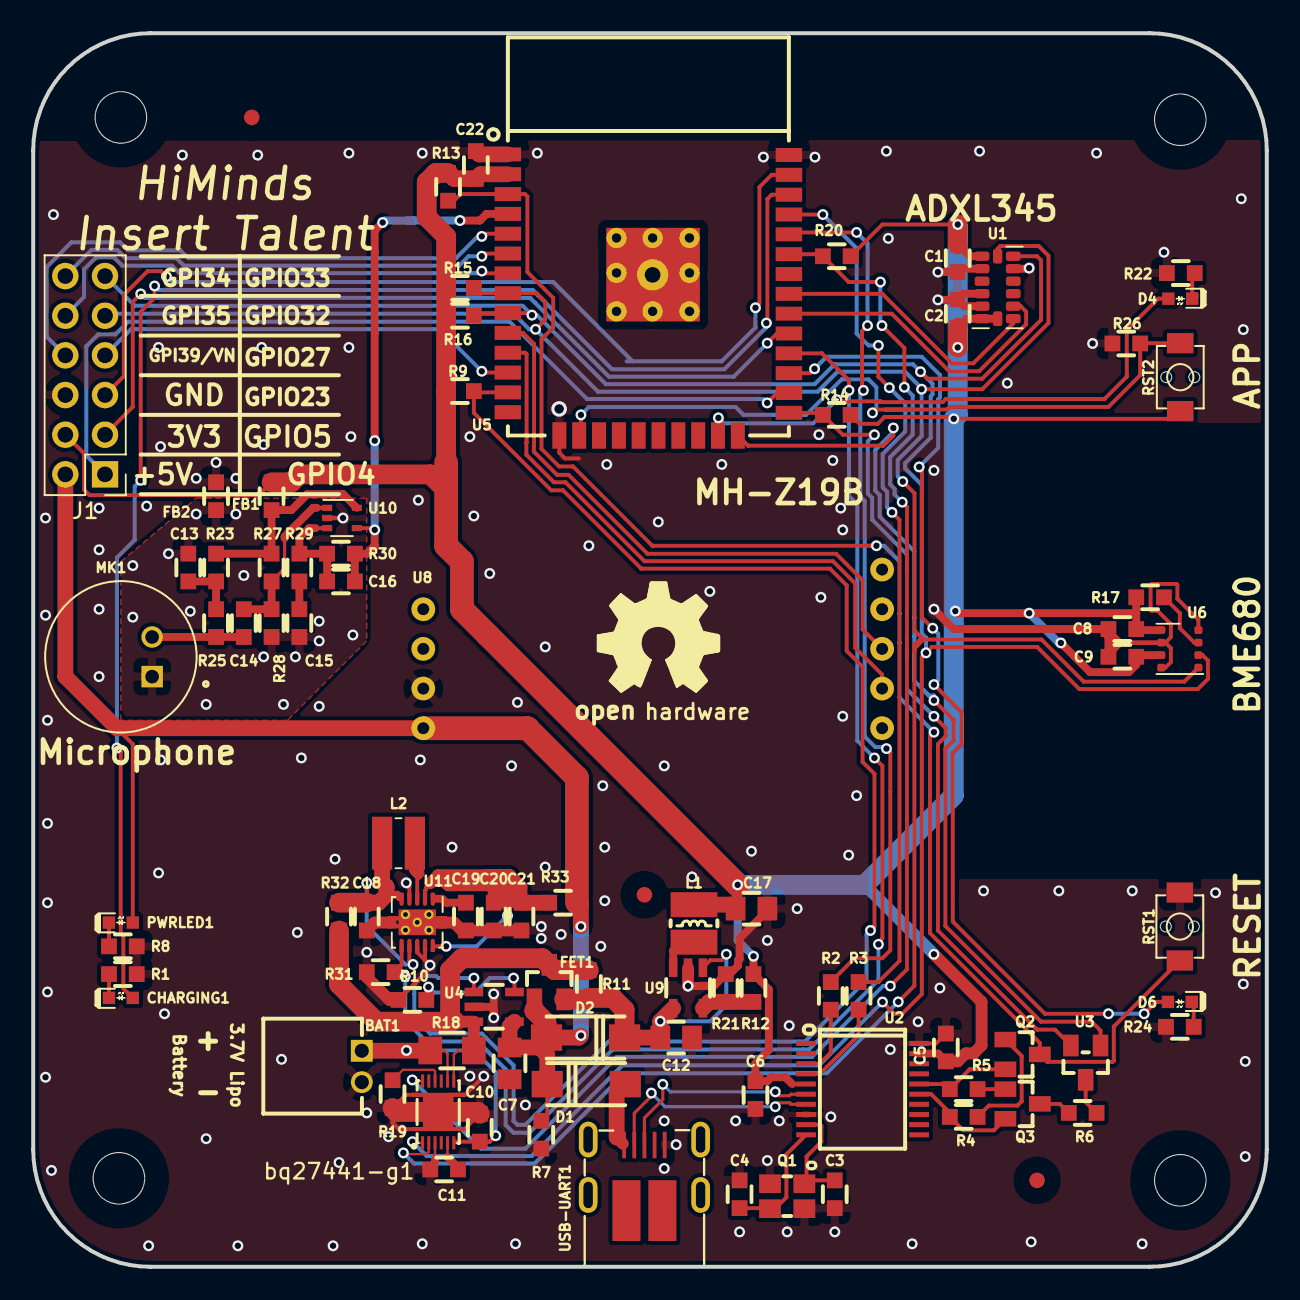
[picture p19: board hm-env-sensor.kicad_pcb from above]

Board: 2 copper layers, 79.0 x 79.0 mm, 93 parts (0 on the bottom side), 66 nets.

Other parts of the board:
MountingHole*: Mounting_hole_3.3mm
MountingHole*#2, MountingHole*#3, MountingHole*#4: Mounting_hole_3.3mm

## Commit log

2019-11-23 added KiCad EDA files
    added KiCad EDA files
    [hm-env-sensor.kicad_pcb, hm-env-sensor.ods, hm-env-sensor.sch]
2020-01-20 Added folder with production files
    [hm-env-sensor-B_Cu.gbr, hm-env-sensor-B_Mask.gbr, hm-env-sensor-B_Paste.gbr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]
2020-11-03 Rev B updates
    [ADXL345.sch, BL4054B_SY808Q.sch, BME680.sch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]
2020-11-05 added BOM
    [hm-env-sensor-bom.xls]
2020-11-06 Update BOM
    [hm-env-sensor-bom.xls, hm-env-sensor-bom_rev2.xls]
